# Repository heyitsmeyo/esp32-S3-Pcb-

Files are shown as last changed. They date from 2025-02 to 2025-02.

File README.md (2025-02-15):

# This is a custom esp32-s3 pcb design : 

# Software Used for the design :  Kicad 



The pcb comes with 4 layers : The top and bottom layers are used for routing gpio pins with the mcu and other components ( resistors , capacitors , voltage regulator ...) , whereas the other two layers are used for setting GND plane and power routing.



# if you like the project , you can donate us for more : 

    https://ko-fi.com/heyitsmeyo

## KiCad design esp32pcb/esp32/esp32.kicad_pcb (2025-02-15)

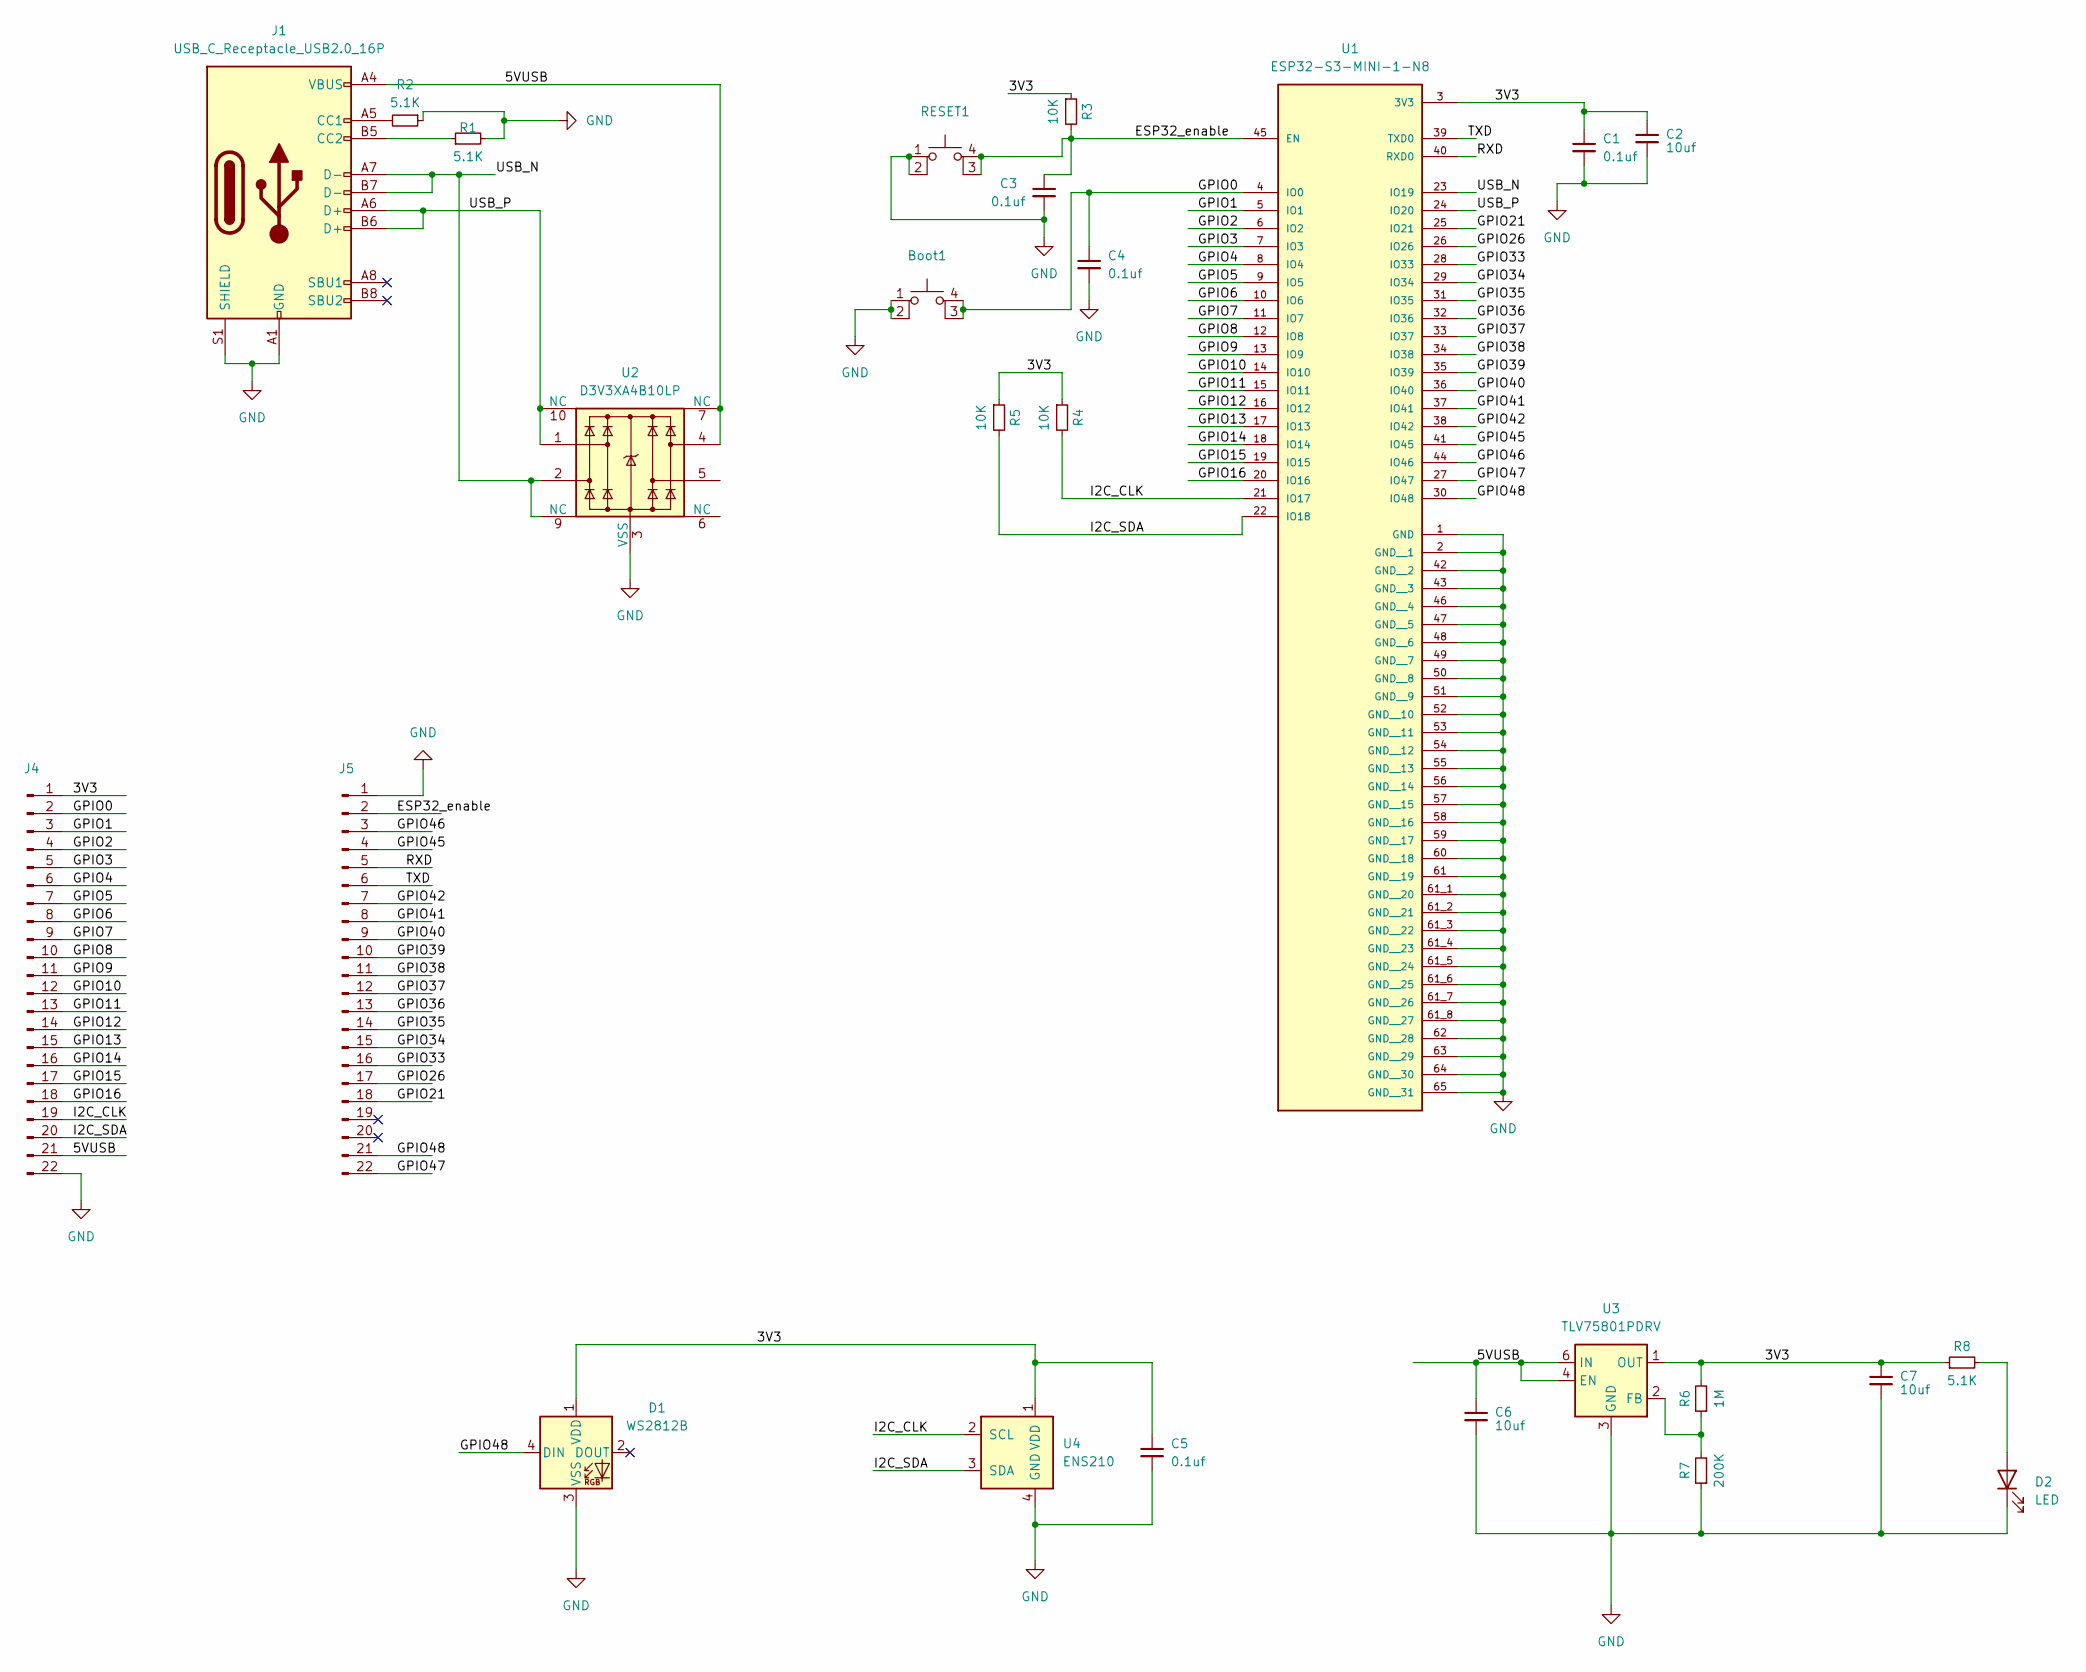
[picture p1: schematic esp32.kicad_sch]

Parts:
Boot1: SW_SPST_PTS810
C1, C3, C4, C5: 0.1uf; C_0201_0603Metric
C2, C6, C7: 10uf; C_0201_0603Metric
D1: WS2812B; LED_WS2812B_PLCC4_5.0x5.0mm_P3.2mm
D2: LED; D_0201_0603Metric
J1: USB_C_Receptacle_USB2.0_16P; USB_C_Receptacle_GCT_USB4105-xx-A_16P_TopMnt_Horizontal
J4, J5: PinHeader_1x22_P2.54mm_Vertical
R1, R2, R8: 5.1K; R_0603_1608Metric
R3, R4, R5: 10K; R_0603_1608Metric
R6: 1M; R_0603_1608Metric
R7: 200K; R_0603_1608Metric
RESET1: SW_SPST_PTS810
U1: ESP32-S3-MINI-1-N8; XCVR_ESP32-S3-MINI-1-N8; PARTREV v0.6
U2: D3V3XA4B10LP; Diodes_UDFN-10_1.0x2.5mm_P0.5mm
U3: TLV75801PDRV; WSON-6-1EP_2x2mm_P0.65mm_EP1x1.6mm
U4: ENS210; AMS_QFN-4-1EP_2x2mm_P0.95mm_EP0.7x1.6mm

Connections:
/3V3: C1.1, C2.1, C5.1, C7.1, D1.1 (VDD), J4.1, R3.1, R4.1, R5.1, R6.2, R8.1, U1.3 (3V3), U3.1 (OUT), U4.1 (VDD)
/5VUSB: C6.1, J1.A4 (VBUS), J1.A9 (VBUS), J1.B4 (VBUS), J1.B9 (VBUS), J4.21, U2.4, U2.7 (NC), U3.4 (EN), U3.6 (IN)
/ESP32_enable: C3.1, J5.2, R3.2, RESET1.3 (K), RESET1.4 (A), U1.45 (EN); also elsewhere on the board
/GPIO0: Boot1.3 (K), Boot1.4 (A), C4.1, J4.2, U1.4 (IO0)
/GPIO1: J4.3, U1.5 (IO1)
/GPIO2: J4.4, U1.6 (IO2)
/GPIO3: J4.5, U1.7 (IO3)
/GPIO4: J4.6, U1.8 (IO4)
/GPIO5: J4.7, U1.9 (IO5)
/GPIO6: J4.8, U1.10 (IO6)
/GPIO7: J4.9, U1.11 (IO7)
/GPIO8: J4.10, U1.12 (IO8)
/GPIO9: J4.11, U1.13 (IO9)
/GPIO10: J4.12, U1.14 (IO10)
/GPIO11: J4.13, U1.15 (IO11)
/GPIO12: J4.14, U1.16 (IO12)
/GPIO13: J4.15, U1.17 (IO13)
/GPIO14: J4.16, U1.18 (IO14)
/GPIO15: J4.17, U1.19 (IO15)
/GPIO16: J4.18, U1.20 (IO16)
/GPIO21: J5.18, U1.25 (IO21)
/GPIO26: J5.17, U1.26 (IO26)
/GPIO33: J5.16, U1.28 (IO33)
/GPIO34: J5.15, U1.29 (IO34)
/GPIO35: J5.14, U1.31 (IO35)
/GPIO36: J5.13, U1.32 (IO36)
/GPIO37: J5.12, U1.33 (IO37)
/GPIO38: J5.11, U1.34 (IO38)
/GPIO39: J5.10, U1.35 (IO39)
/GPIO40: J5.9, U1.36 (IO40)
/GPIO41: J5.8, U1.37 (IO41)
/GPIO42: J5.7, U1.38 (IO42)
/GPIO45: J5.4, U1.41 (IO45)
/GPIO46: J5.3, U1.44 (IO46)
/GPIO47: J5.22, U1.27 (IO47)
/GPIO48: D1.4 (DIN), J5.21, U1.30 (IO48)
/I2C_CLK: J4.19, R4.2, U1.21 (IO17), U4.2 (SCL)
/I2C_SDA: J4.20, R5.2, U1.22 (IO18), U4.3 (SDA)
/RXD: J5.5, U1.40 (RXD0)
/TXD: J5.6, U1.39 (TXD0)
/USB_N: J1.A7 (D-), J1.B7 (D-), U1.23 (IO19), U2.2, U2.9 (NC)
/USB_P: J1.A6 (D+), J1.B6 (D+), U1.24 (IO20), U2.1, U2.10 (NC)
GND: Boot1.1, Boot1.2, C1.2, C2.2, C3.2, C4.2, C5.2, C6.2, C7.2, D1.3 (VSS), D2.1 (K), J1.A1 (GND), J1.A12 (GND), J1.B1 (GND), J1.B12 (GND), J1.S1 (SHIELD), J4.22, J5.1, R1.2, R2.1, R7.1, RESET1.1, RESET1.2, U1.1 (GND), U1.2 (GND__1), U1.42 (GND__2), U1.43 (GND__3), U1.46 (GND__4), U1.47 (GND__5), U1.48 (GND__6), U1.49 (GND__7), U1.50 (GND__8), U1.51 (GND__9), U1.52 (GND__10), U1.53 (GND__11), U1.54 (GND__12), U1.55 (GND__13), U1.56 (GND__14), U1.57 (GND__15), U1.58 (GND__16), U1.59 (GND__17), U1.60 (GND__18), U1.61 (GND__19), U1.61_1 (GND__20), U1.61_2 (GND__21), U1.61_3 (GND__22), U1.61_4 (GND__23), U1.61_5 (GND__24), U1.61_6 (GND__25), U1.61_7 (GND__26), U1.61_8 (GND__27), U1.62 (GND__28), U1.63 (GND__29), U1.64 (GND__30), U1.65 (GND__31), U2.3 (VSS), U2.8 (VSS), U3.3 (GND), U3.7 (GND), U4.4 (GND), U4.5 (GND); also elsewhere on the board
unnamed: D2.2 (A), R8.2
unnamed: J1.A5 (CC1), R2.2
unnamed: J1.B5 (CC2), R1.1
unnamed: R6.1, R7.2, U3.2 (FB)

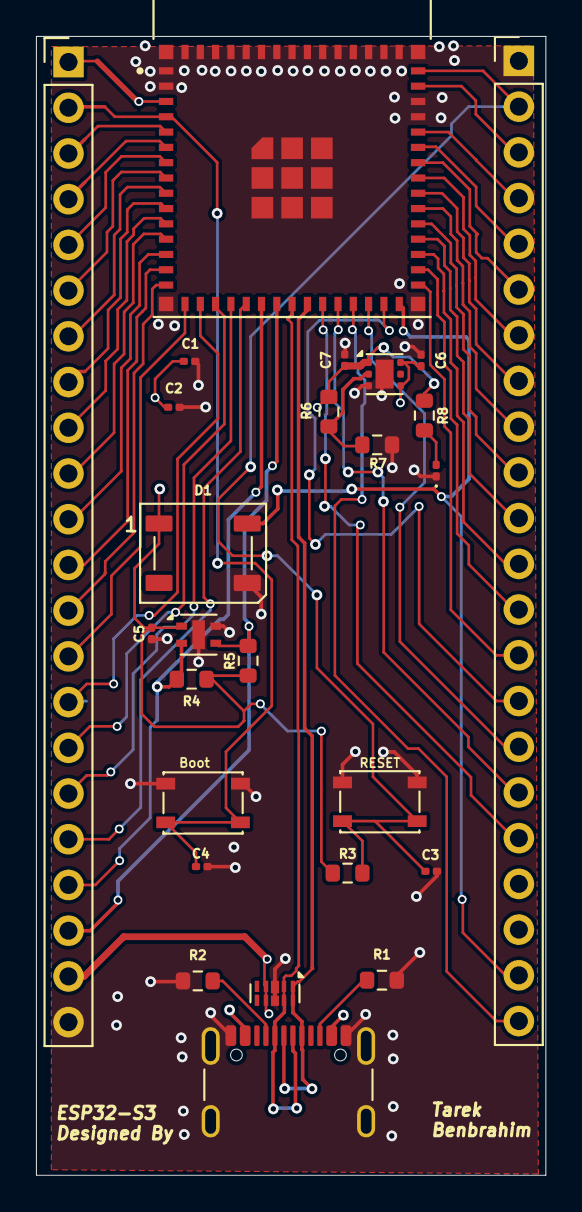
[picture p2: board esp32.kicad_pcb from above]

Board: 4 copper layers, 28.3 x 63.3 mm, 26 parts (0 on the bottom side), 47 nets.

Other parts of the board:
RESET: SW_SPST_PTS810

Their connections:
/ESP32_enable: RESET.3 (K), RESET.4 (A); also elsewhere on the board
GND: RESET.1, RESET.2; also elsewhere on the board
